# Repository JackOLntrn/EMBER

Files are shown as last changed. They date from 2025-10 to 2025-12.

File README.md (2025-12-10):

# EMBER
## Overview
The EMBER project makes use of the a thermal IR camera to detect fires on a pan/tilt motor mechanism. Once a fire is detected, the system points the thermal camera/hose nozzle at the detected fire and activates a solenoid to spray water at the detected fire. The system is supplied with water from a garden hose. This repository includes all of the relavant files for the project. 
| Directory | Contents|
| --- | --- |
| [EMBER/src](src/) | Contains the header and cpp files developed for the project |
| [EMBER/hardware/board](hardware/board) | Contains the schematic board and gerber files used to develop a custom PCB used for the project|
| [EMBER/hardware/mech](hardware/mech) | Contains the 3D model files of parts developed for the project |
| [EMBER/docs](docs/) | Contains doxygen generated documents for code documentation |

See board documentation [here](hardware/board/README.md)

See mechanical component documentation [here](hardware/mech/README.md)

See code documentation [here](https://jackolntrn.github.io/EMBER/)

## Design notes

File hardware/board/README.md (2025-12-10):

# EMBER Board Design

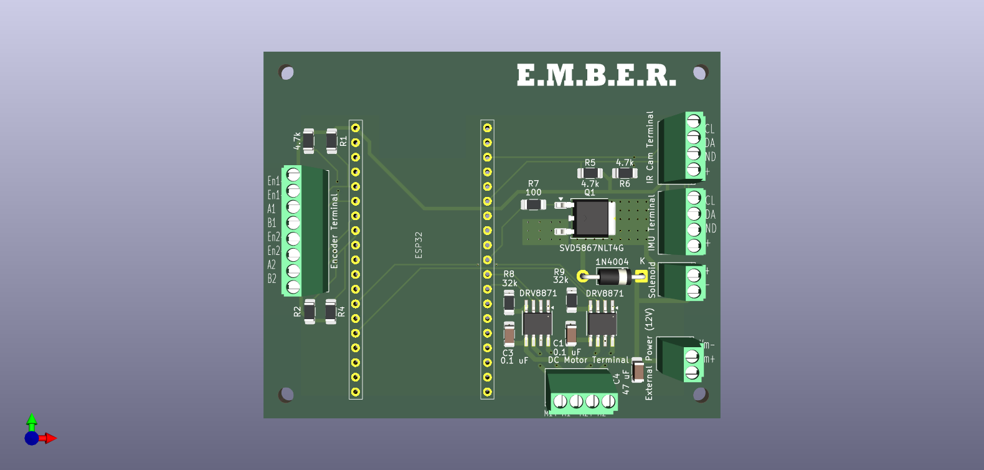
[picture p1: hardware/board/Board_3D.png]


This folder contains the schematic and pcb files for EMBER.

The board has the following terminals for connection to hardware:

| Terminal | Description |
| --- | --- |
| ESP32 Pin Connector | 28 pin connector for connection of ESP32 to the board. |
| Encoder Terminal | 8 position terminal for connection to the 2 motor quadrature encoders. Has 3.3V+ and gnd output for both terminals denoted by Eni+ and Eni- respectively. Has inputs for channels A and B. |
| DC Motor Terminal | 4 position terminal to connect the 2 motors. Ensure that motor 1's encoder is connected to channels A1 and B1 on the encoder terminal, and motor 2's encoder is connected to channels A2 and B2 on the encoder terminal. |
| IR Cam Terminal | 4 position terminal for I2C connection to the MLX90640 Thermal IR Camera. Has 3.3V+ and gnd output and SDA/SCL input. |
| IMU Terminal | 4 position terminal to support an additional I2C peripheral, for instance an IMU. Has 3.3V+ and gnd output and SDA/SCL input. |
|Solenoid | 2 position terminal for connection to the Solenoid. Outputs Vm+ and Vm- using a MOSFET controlled by the microcontroller with a flyback diode circuit. |
| External Power (12V) | 2 position terminal for connection to battery. Vm+ should be ~12V+ and Vm- should be gnd. |

### Board
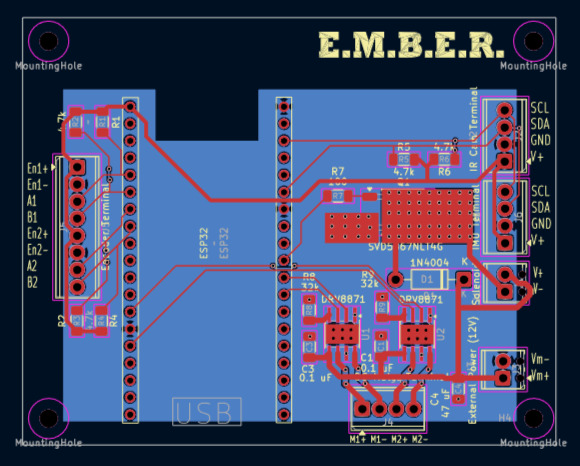
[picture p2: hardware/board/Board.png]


## Schematic
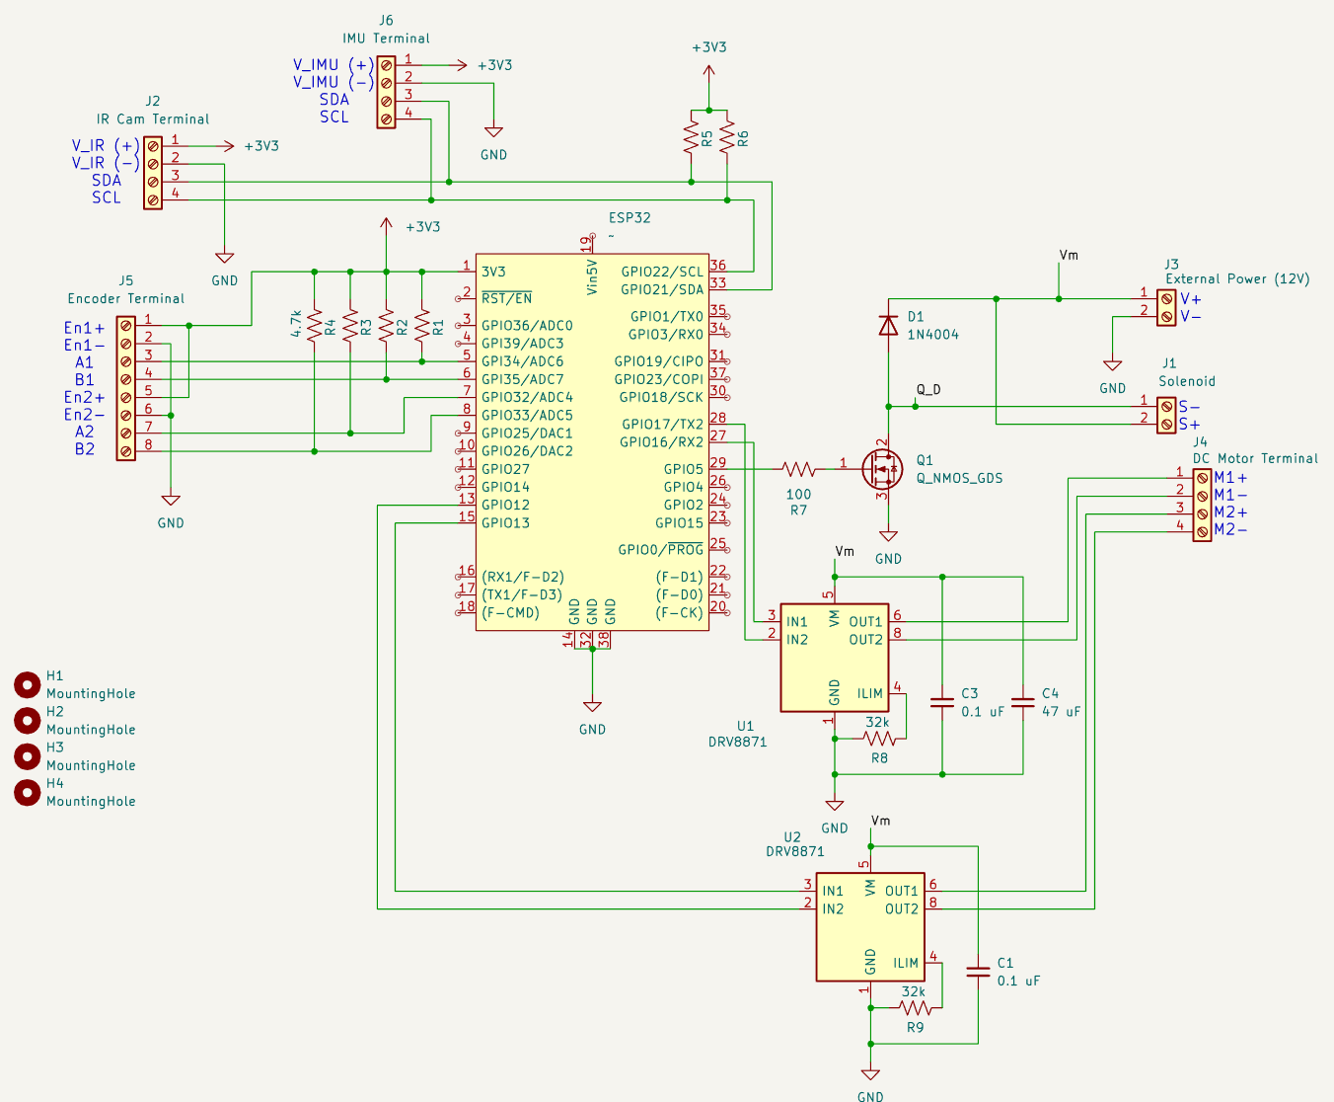
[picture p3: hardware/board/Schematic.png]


## Board Componenets

### 1. ESP32 NODEMCU-32S ESP-32S Kit x1
Main microcontroller for project - AliExpress: [NodeMCU ESP-32S](https://www.aliexpress.us/item/3256803993966716.html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)

### 2. DRV8871DDAR - Motor Driver x2
Motor driver with 2 inputs from controller for PWM control - Texas Instruments: [DRV8871DDAR](https://www.digikey.com/en/products/detail/texas-instruments/DRV8871DDAR/5639726)

### 3. 1N4004 Diode
Flyback Diode for Solenoid/MOSFET circuit : [1N4004-E3/54](https://www.digikey.com/en/products/detail/diotec-semiconductor/1N4004/13164524)

### 4. MOSFET N-CH x1
MOSFET to turn solenoid on/off from microcontroller N-Channel 60 V 22A (Tc) 3.3W (Ta), 43W (Tc) - Onsemi: [SVD5867NLT4G](https://www.digikey.com/en/products/detail/onsemi/SVD5867NLT4G/3062534)

### 5. 100Ω Resistor x1
Resistor between microcontroller and MOSFET gate - Vishay Dale: [TNPW1206100RBEEA](https://www.digikey.com/en/products/detail/vishay-dale/TNPW1206100RBEEA/1607739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)

### 6. 4.7kΩ Resistor x6
Pullup Resistors for I2C circuit and Encoder Channels - YAGEO: [RC1206FR-074K7L](https://www.digikey.com/en/products/detail/yageo/RC1206FR-074K7L/728887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)

### 7. 32kΩ Resistor x2
Current limit resistor for motor drivers (limitting to 2A, under the motor stall current to protect motors) - KOA Speer Electronics, Inc: [RN73H2BTTD3202F100](https://www.digikey.com/en/products/detail/koa-speer-electronics-inc/RN73H2BTTD3202F100/10098378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)

### 8. 47μF Capacitor x1
Filter capacitor for motor drivers - TDK Corporation: [C3216X5R1E476M160DC](https://www.digikey.com/en/products/detail/tdk-corporation/C3216X5R1E476M160DC/22106052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)

### 9. 0.1μF Capacitor x2
Filter capacitor for motor drivers - KEMET: [C1206C104K5RACTU](https://www.digikey.com/en/products/detail/kemet/C1206C104K5RACTU/411248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)

### 10. 2 Position Screw Terminal x2
12V power in and Solenoid power out terminals - Phoenix Contact: [1725656](https://www.digikey.com/en/products/detail/phoenix-contact/1725656/267462)

### 11. 4 Position Screw Terminal x3
I2C connections (2 were added for potential to integrate another I2C peripheral such as an IMU, although only 1 is used for Thermal IR camera), and motor output connection - Phoenix Contact: [1725672](https://www.digikey.com/en/products/detail/phoenix-contact/1725672/267464)

### 12. 8 Position Screw Terminal x1
Encoder connections - Phoenix Contact: [1725711](https://www.digikey.com/en/products/detail/phoenix-contact/1725711/267468)

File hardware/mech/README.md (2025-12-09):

EMBER Mechanical Components 
======
This folder contains the mechanical assembly for EMBER and its associated components. 

Custom Solidworks Files
------

### [1. EMBER Assembly](../mech/EMBER.SLDASM)
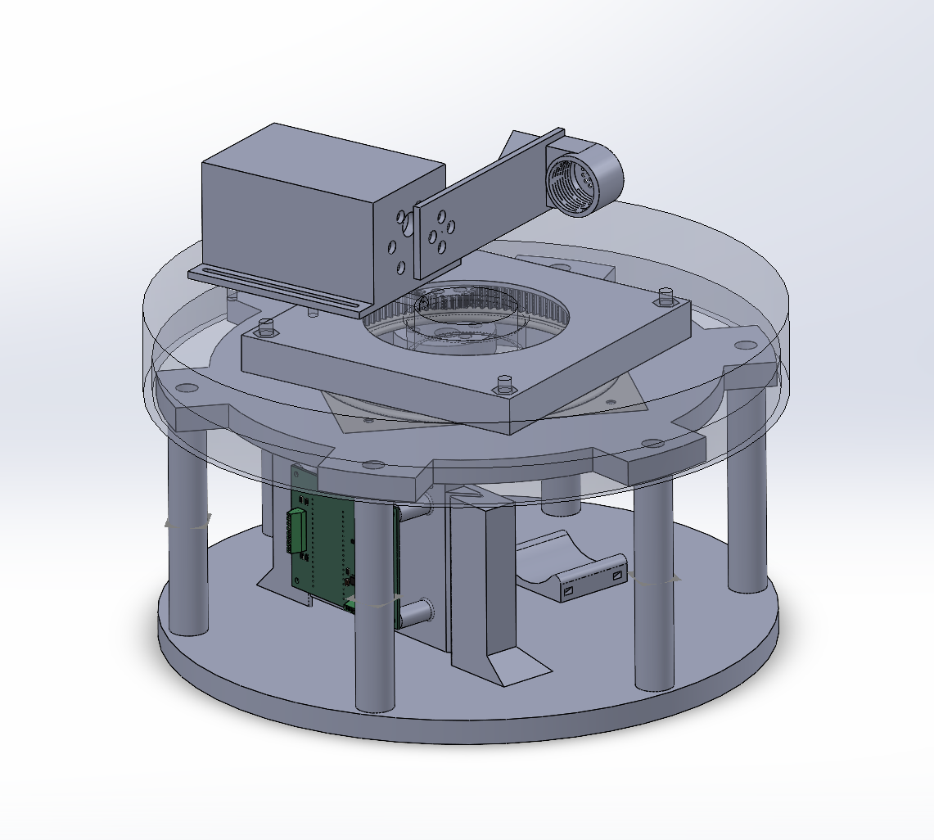
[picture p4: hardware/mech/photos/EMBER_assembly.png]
Solidworks Assembly View


The main assembly file, contains all the relevant piece parts mated to visualize real world model.

### 2. EMBER Board
Model of the custom PCB exported from KiCAD for fitting.

QTY: 1

### 3. EMBER Base Enclosure
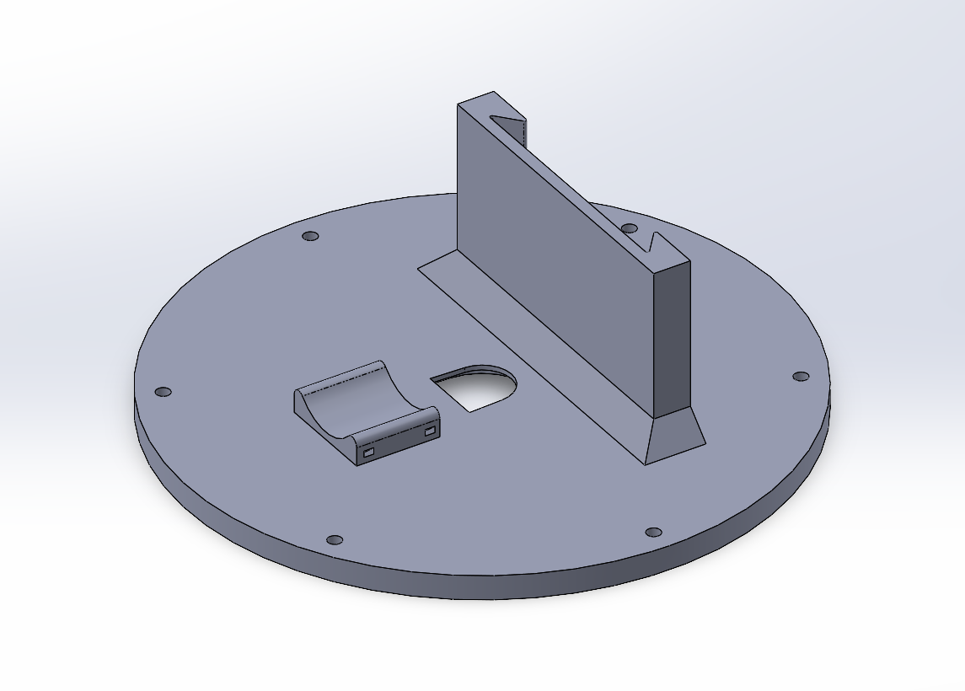
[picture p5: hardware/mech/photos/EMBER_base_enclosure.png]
Base Enclosure


Main part that seats all parts and holds the solenoid valve.

QTY: 1

### 4. EMBER Base Lid 1
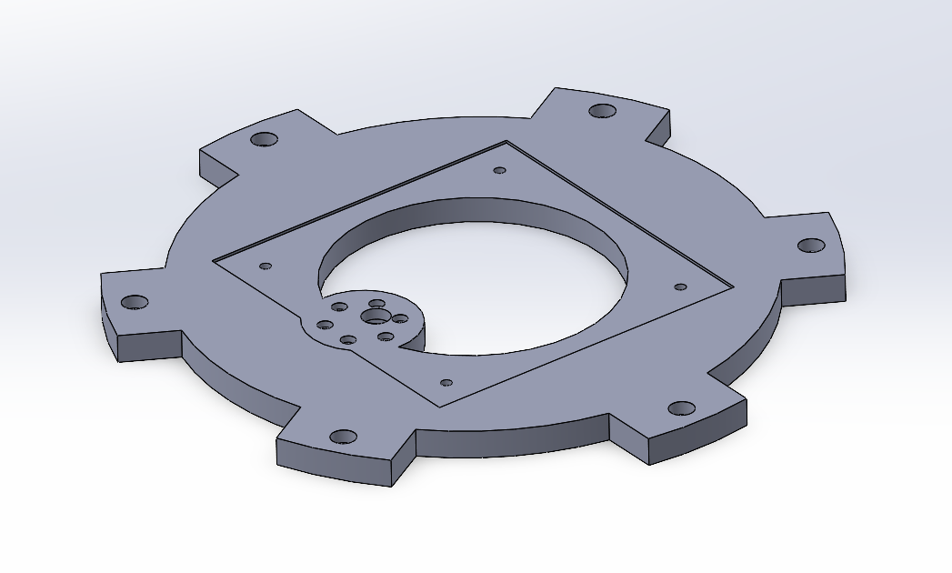
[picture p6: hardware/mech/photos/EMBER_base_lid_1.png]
Base Lid 1


Large circular plate that mounts the pan motor and connects enclosure supports to the turntable.

QTY: 1

### 5. EMBER Board Mount
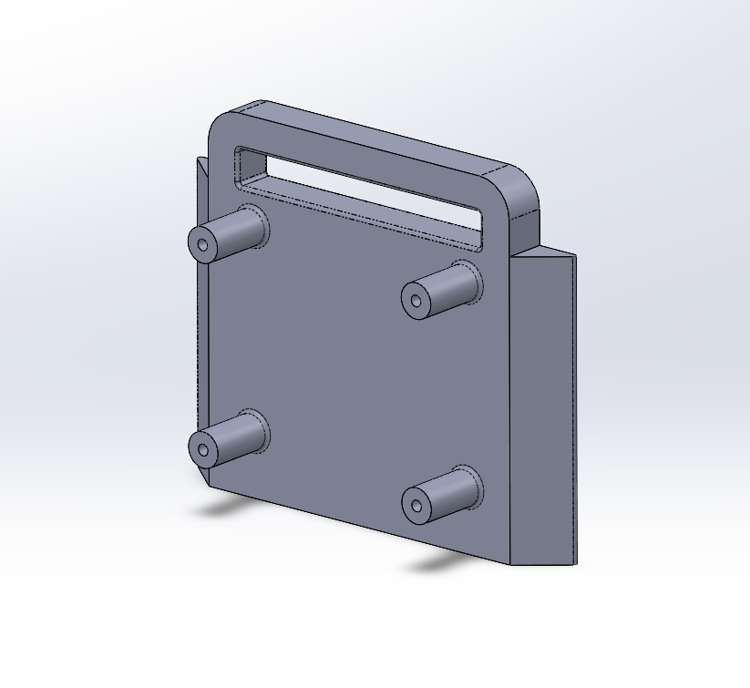
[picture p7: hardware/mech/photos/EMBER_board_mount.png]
Board Mount


Piece that has standoffs for the PCB and holds in place using dovetail slot on base enclosure.

QTY: 1

### 6. EMBER Enclosure Supports
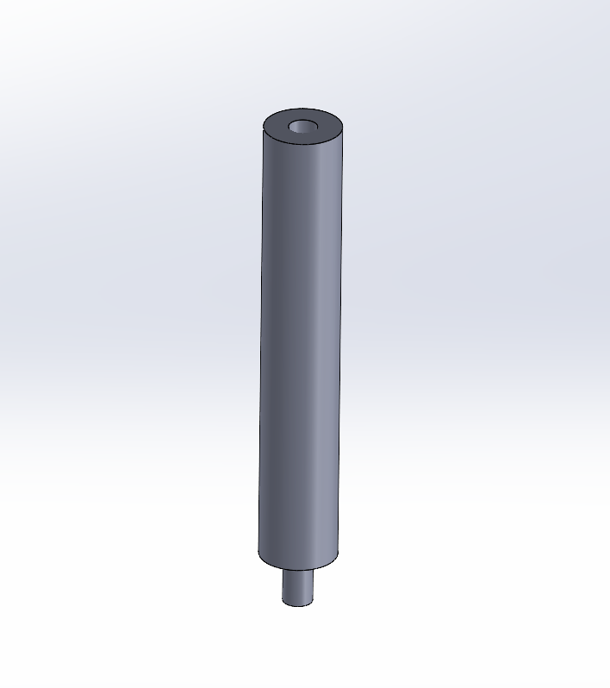
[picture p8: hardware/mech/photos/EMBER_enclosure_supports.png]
Enclosure Support


Supports all components connected to the upper base lid and above.

QTY: 6

### 7. EMBER Hose Boom Arm
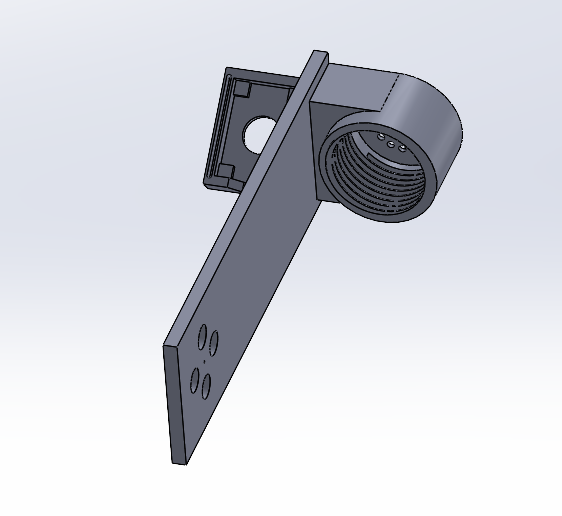
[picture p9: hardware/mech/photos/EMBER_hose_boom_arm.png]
Hose Boom Arm


Mechanical arm that mounts to tilt motor D shaft coupling and mounts IR camera and flexible hose end.

QTY: 1

### 8. EMBER Hose Nozzle
Test file to ensure threads fit the purchased mechanical parts. Not in final assembly.

QTY: 1

### 9. EMBER IR Camera Cover
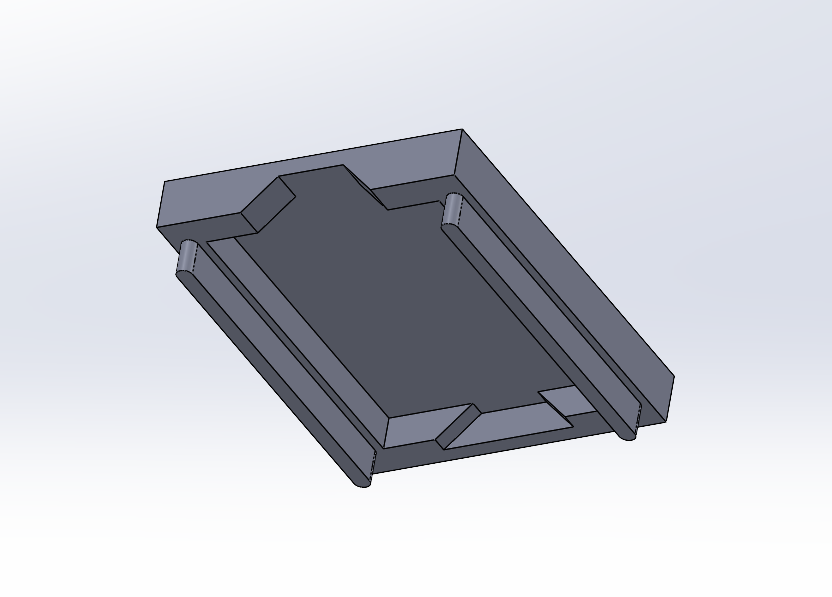
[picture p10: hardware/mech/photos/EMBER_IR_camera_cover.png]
IR Camera Cover


Snap fit cover for the IR camera when seated into the hose boom arm.

QTY: 1

### 10. EMBER Pan Motor Gear
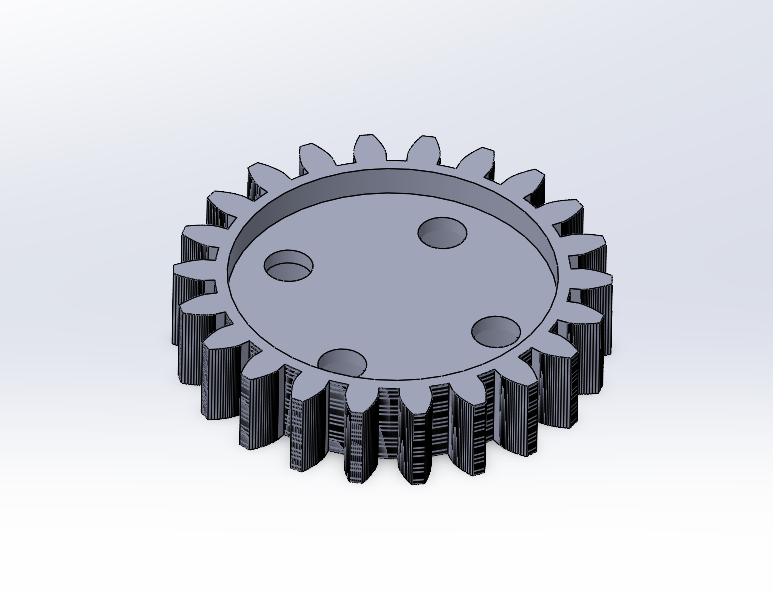
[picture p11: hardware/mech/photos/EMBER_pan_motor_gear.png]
Pan Motor Gear


22-tooth external gear mounted to pan motor D shaft coupling and rotates with the internal teeth on top platform.

QTY: 1

### 11. EMBER Tilt Motor Mount
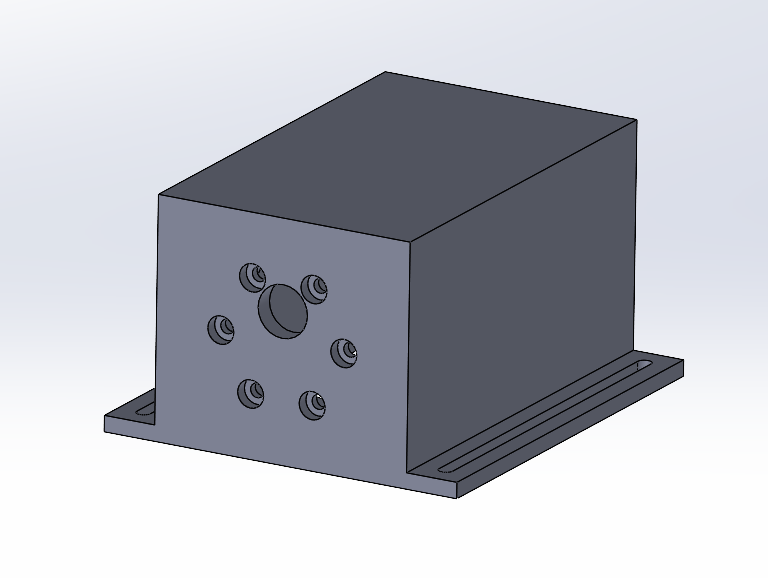
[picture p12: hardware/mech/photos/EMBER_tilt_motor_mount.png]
Tilt Motor Mount


Tilt motor mounting that has slots and fastened onto top platform with motor mount. 

QTY: 1

### 12. EMBER Top Platform with Motor Mount
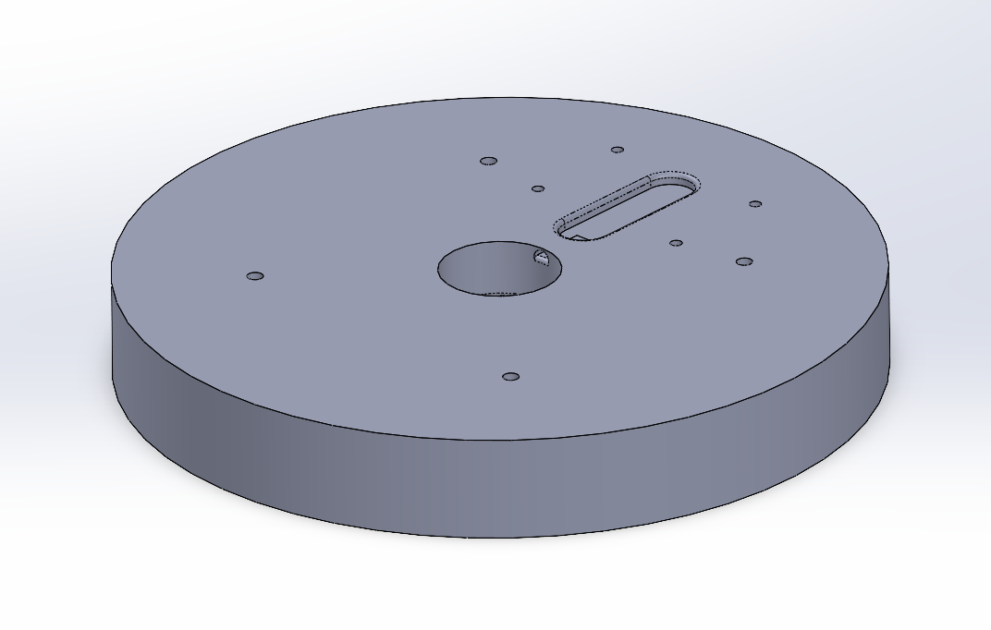
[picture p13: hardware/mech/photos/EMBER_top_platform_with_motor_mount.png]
Top Platform with Motor Mount


Cover that seats above top platform and has features to connect tilt motor mount onto it.

QTY: 1

### 13. EMBER Top Platform
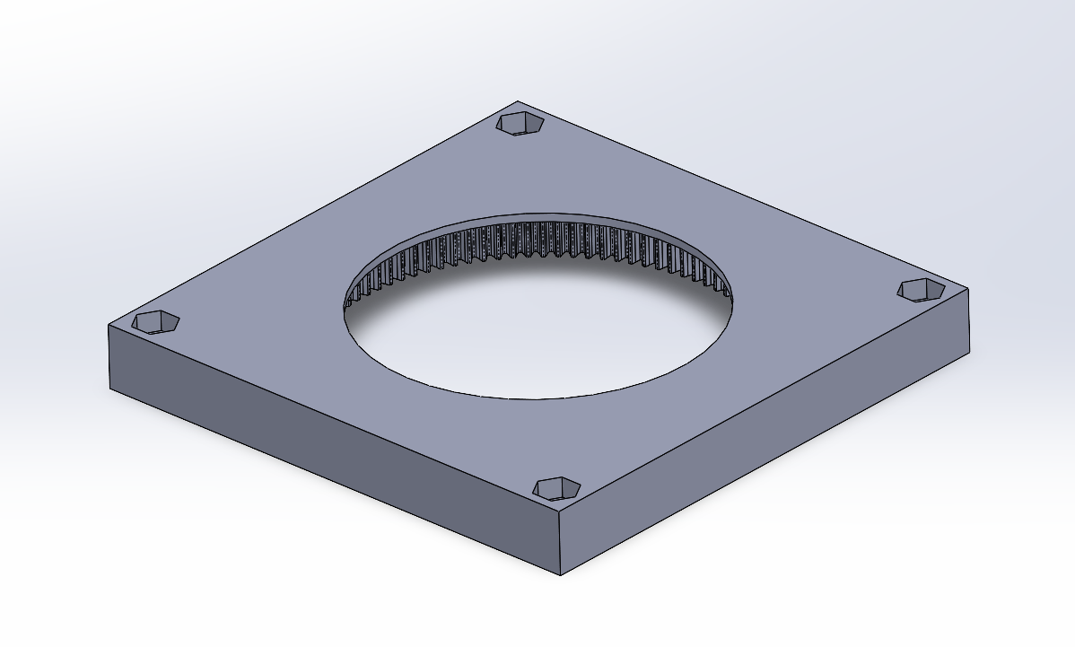
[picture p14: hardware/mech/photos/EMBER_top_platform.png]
Top Platform


Internal teeth gear that mounts onto top of lubricated turntable. 

QTY: 1

### 14. 1544T1 Lubricated Turntable
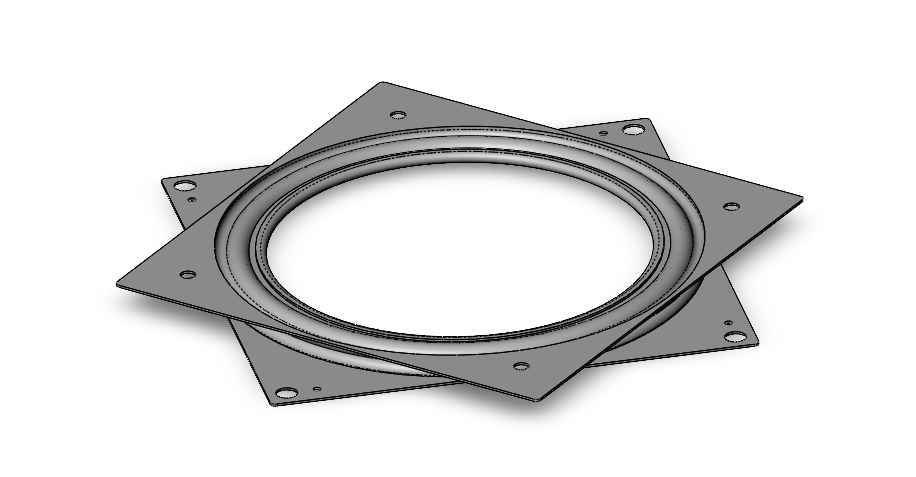
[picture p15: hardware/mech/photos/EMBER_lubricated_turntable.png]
Lubricated Turntable


Turntable from McMaster Carr used to minimize friction on pan mechanism. 

QTY: 1

Electrical Hardware
------

### [1. 3/4" 12V DC Solenoid Valve - Brass Body Normally Closed, VITON SEAL](https://ussolid.com/products/u-s-solid-electric-solenoid-valve-3-4-12v-dc-solenoid-valve-brass-body-normally-closed-viton-seal-html)
Solenoid valve that connects household hose to internal pipe fittings.

QTY: 1

### [2. 37GB-3530-EN Motor](../mech/37GB-3530-EN_Motor_Spec_Sheet.pdf)
Specification sheet for our selected 12V motor.

QTY: 2

### [3. Adafruit MLX90640 IR Thermal Camera Breakout - 55 Degree](https://www.adafruit.com/product/4407#description)
IR Thermal Camera product page and description.

QTY: 1

Mechanical Hardware
------

### [1. 3/4 in. MNPT x FHT PVC Swivel](https://www.homedepot.com/p/Orbit-3-4-in-MNPT-x-FHT-PVC-Swivel-53364/100197786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)
Connects common household hose to solenoid valve and the solenoid valve to the internal hose.

QTY: 2

### [2. 1/2 in. Barb x 3/4 in. MIP Nylon Adapter Fitting](https://www.homedepot.com/p/Everbilt-1-2-in-Barb-x-3-4-in-MIP-Nylon-Adapter-Fitting-800229/300862694)
Connects solenoid valve to flexible hose and flexible hose to mechanical arm.

QTY: 2

### [3. 1/2 in. I.D. x 5/8 in. O.D. x 10 ft. Clear Vinyl Tubing](https://www.homedepot.com/p/Everbilt-1-2-in-I-D-x-5-8-in-O-D-x-10-ft-Clear-Vinyl-Tubing-T10006010/304185142)
Flexible hose that fits into the nylon barb adapter and supplies water from the hosehold hose to our target.

QTY: 1

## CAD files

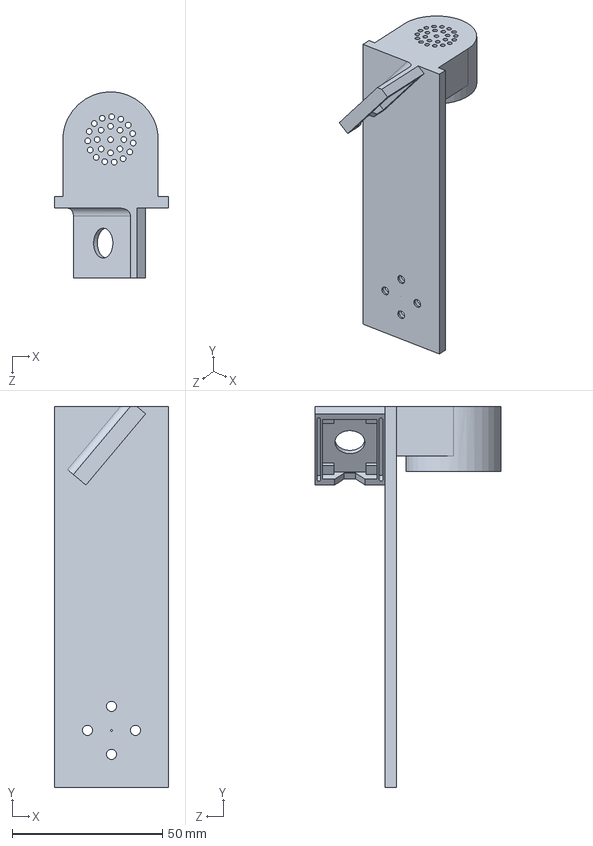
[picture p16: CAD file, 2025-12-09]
hardware/mech/EMBER_Hose Boom Arm.SLDPRT
38.1 x 127.0 x 62.0 mm

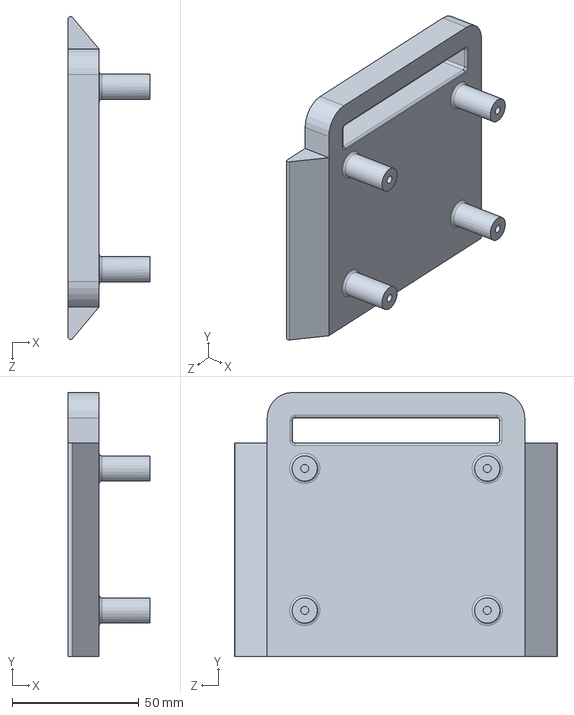
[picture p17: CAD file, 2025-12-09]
hardware/mech/EMBER_Board Mount.SLDPRT
32.3 x 104.2 x 127.4 mm

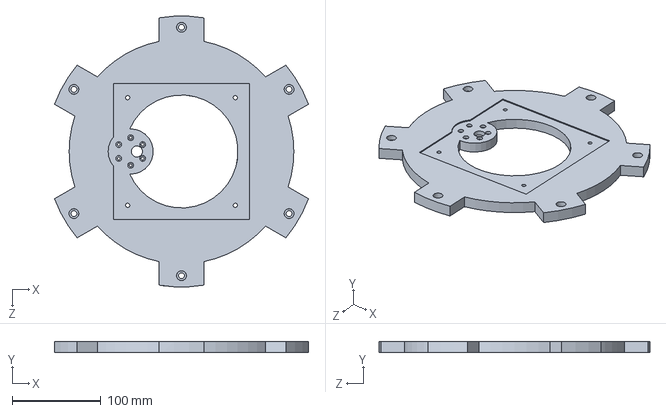
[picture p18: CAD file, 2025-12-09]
hardware/mech/EMBER_Base Lid 1.SLDPRT
285.7 x 12.7 x 304.3 mm

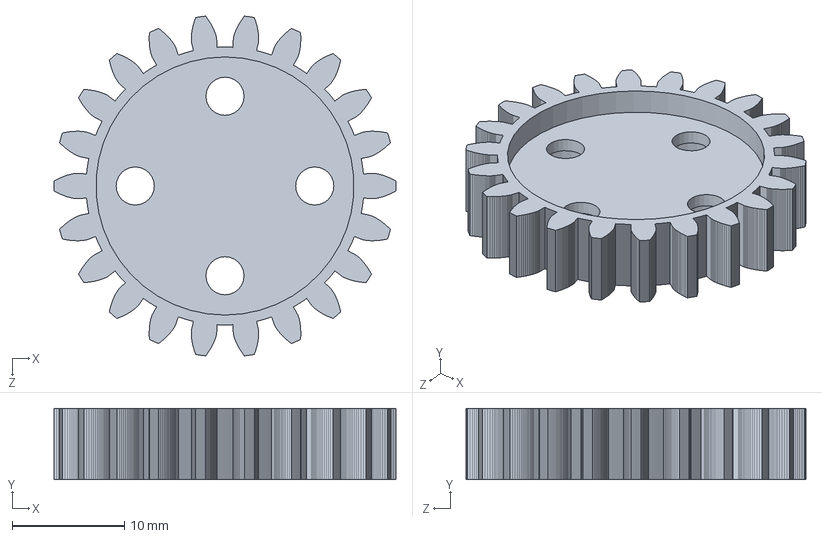
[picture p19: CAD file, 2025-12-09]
hardware/mech/EMBER_Pan Motor Gear.SLDPRT
30.5 x 6.35 x 30.3 mm

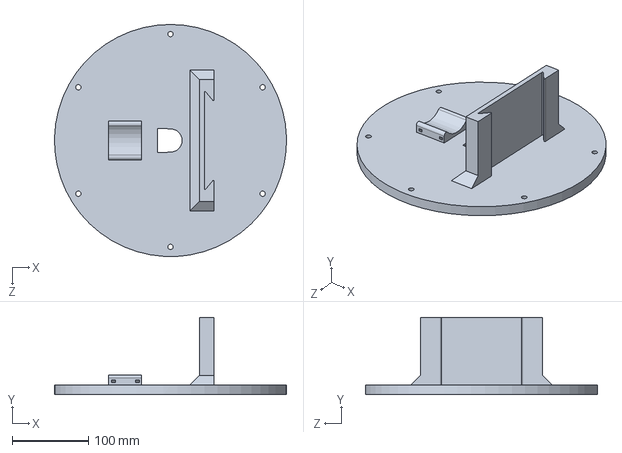
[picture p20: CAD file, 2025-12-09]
hardware/mech/EMBER_Base Enclosure.SLDPRT
304.7 x 101.6 x 304.8 mm

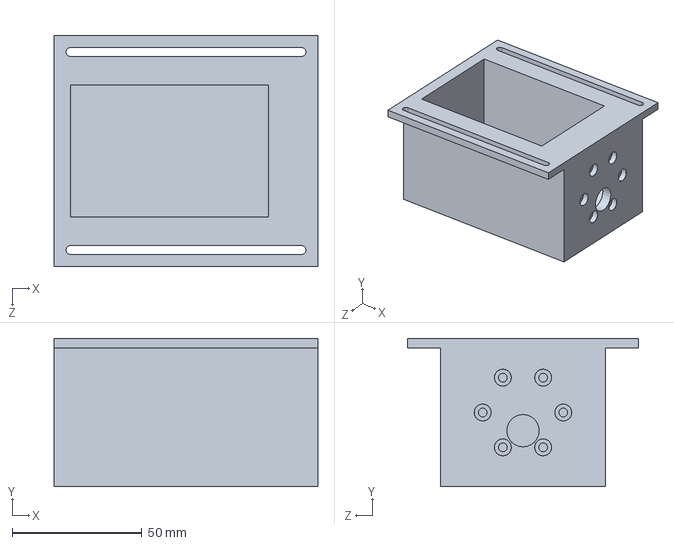
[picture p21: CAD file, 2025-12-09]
hardware/mech/EMBER_Tilt Motor Mount.SLDPRT
101.6 x 57.1 x 88.9 mm

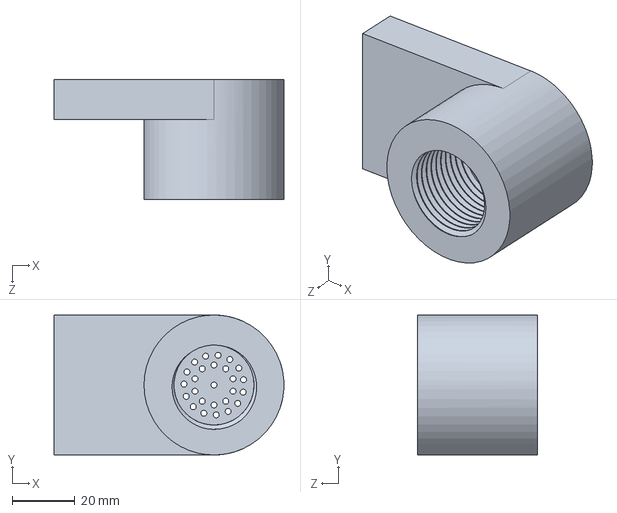
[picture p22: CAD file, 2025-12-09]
hardware/mech/EMBER_Hose Nozzle.SLDPRT
73.0 x 44.5 x 38.1 mm

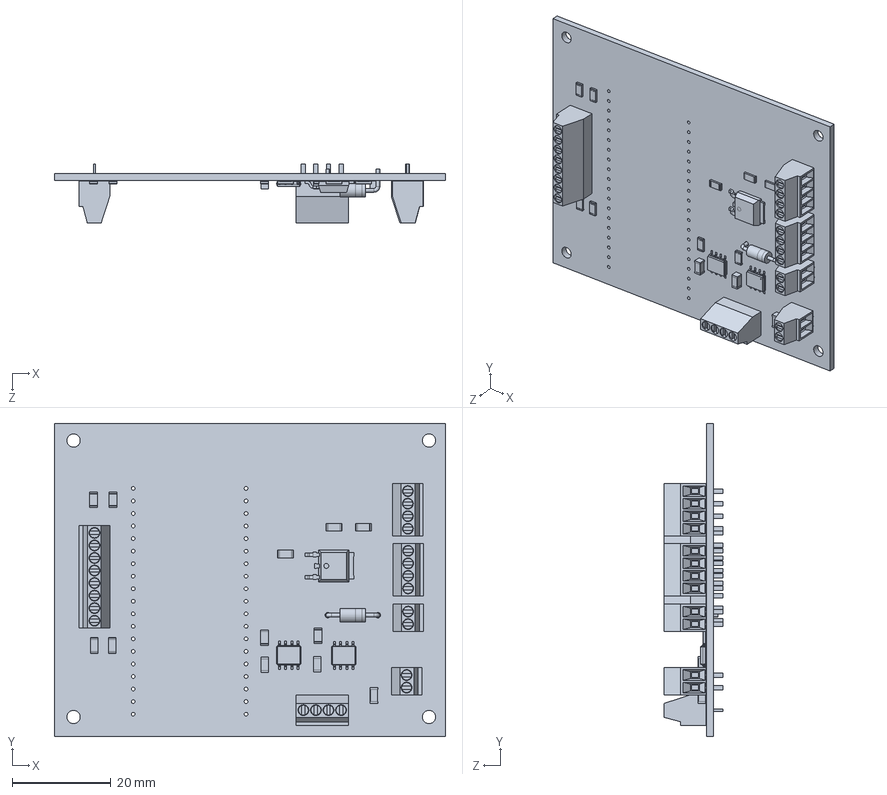
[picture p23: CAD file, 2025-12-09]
hardware/mech/EMBER_BOARD.SLDPRT
79.2 x 63.5 x 12.0 mm

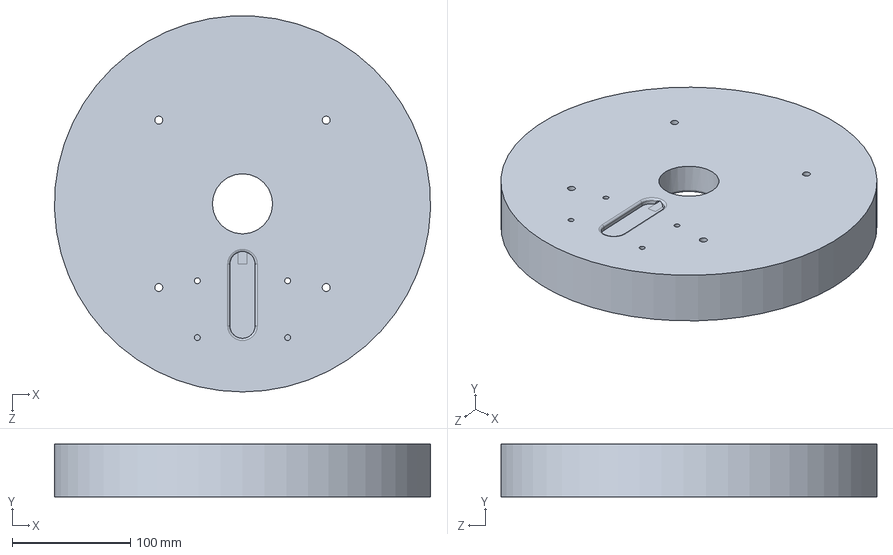
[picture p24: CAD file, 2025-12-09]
hardware/mech/EMBER_Top Platform with Motor Mount.SLDPRT
317.4 x 44.5 x 317.2 mm

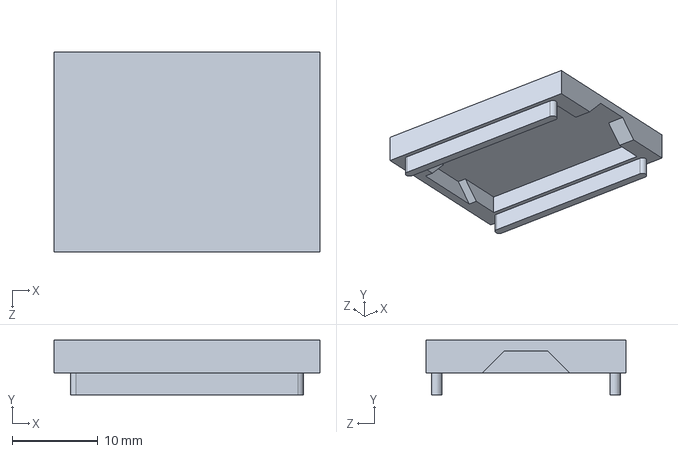
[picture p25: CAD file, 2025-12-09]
hardware/mech/EMBER_IR Camera Cover.SLDPRT
31.0 x 6.35 x 23.3 mm

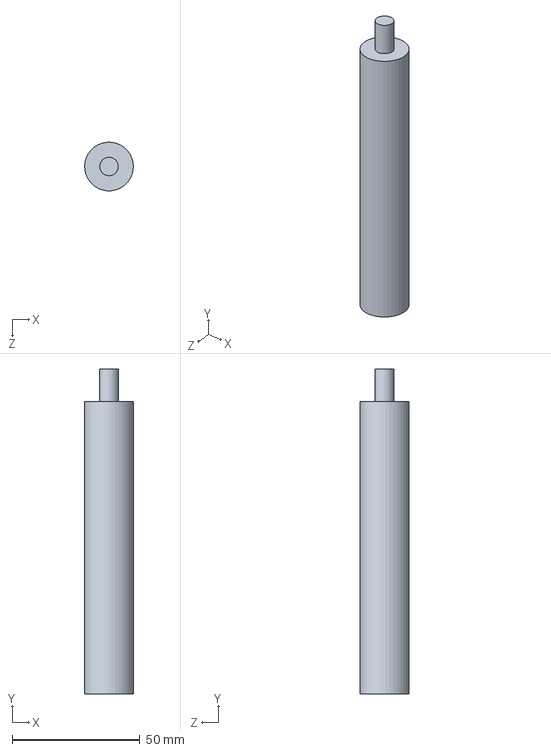
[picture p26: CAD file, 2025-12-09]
hardware/mech/EMBER_Enclosure Supports.SLDPRT
19.0 x 127.0 x 19.1 mm

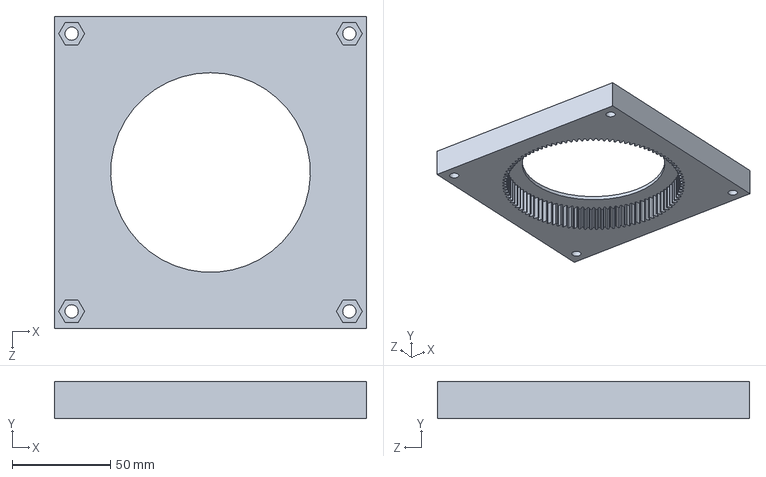
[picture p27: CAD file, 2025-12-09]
hardware/mech/EMBER_Top Platform.SLDPRT
158.8 x 19.1 x 158.8 mm

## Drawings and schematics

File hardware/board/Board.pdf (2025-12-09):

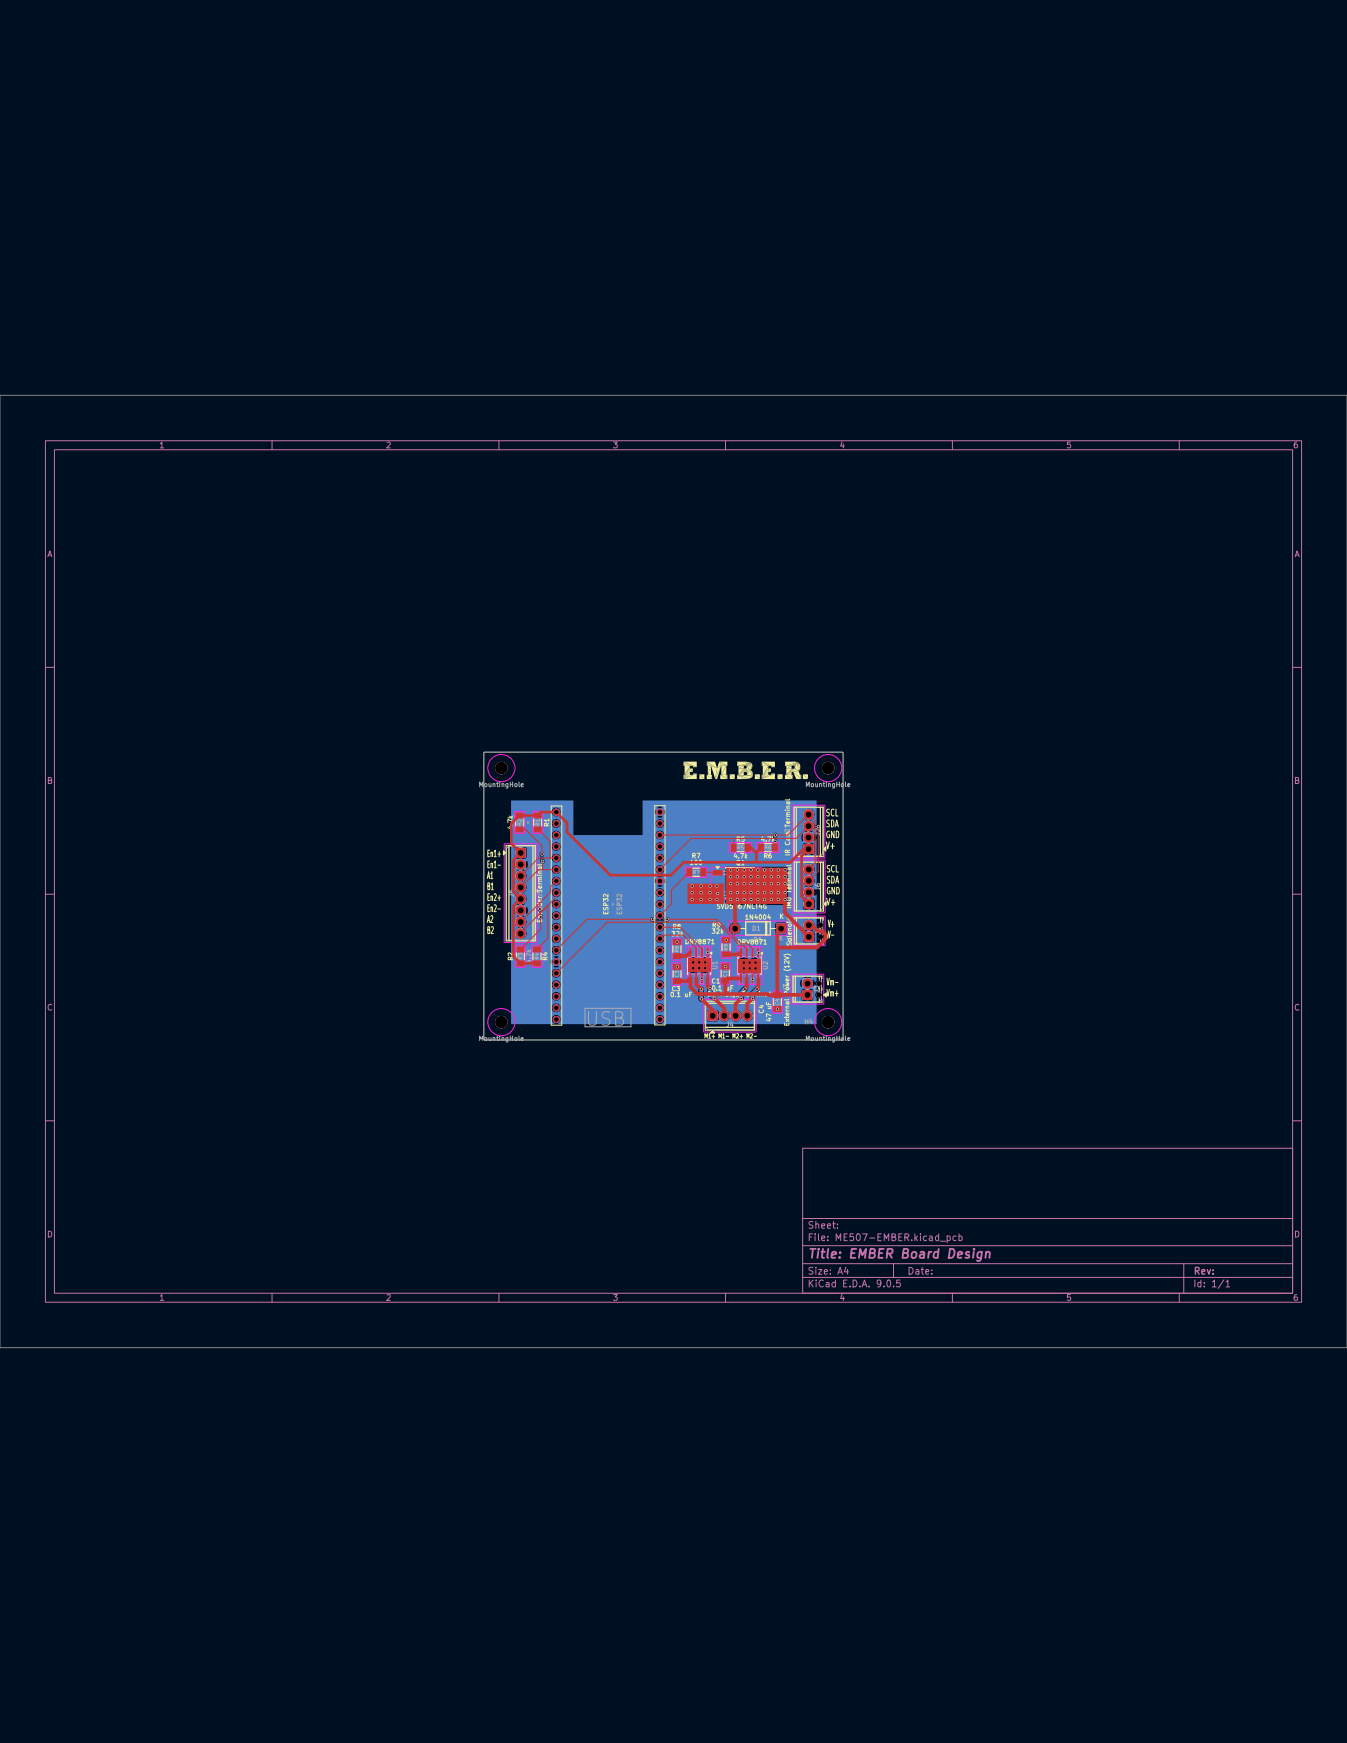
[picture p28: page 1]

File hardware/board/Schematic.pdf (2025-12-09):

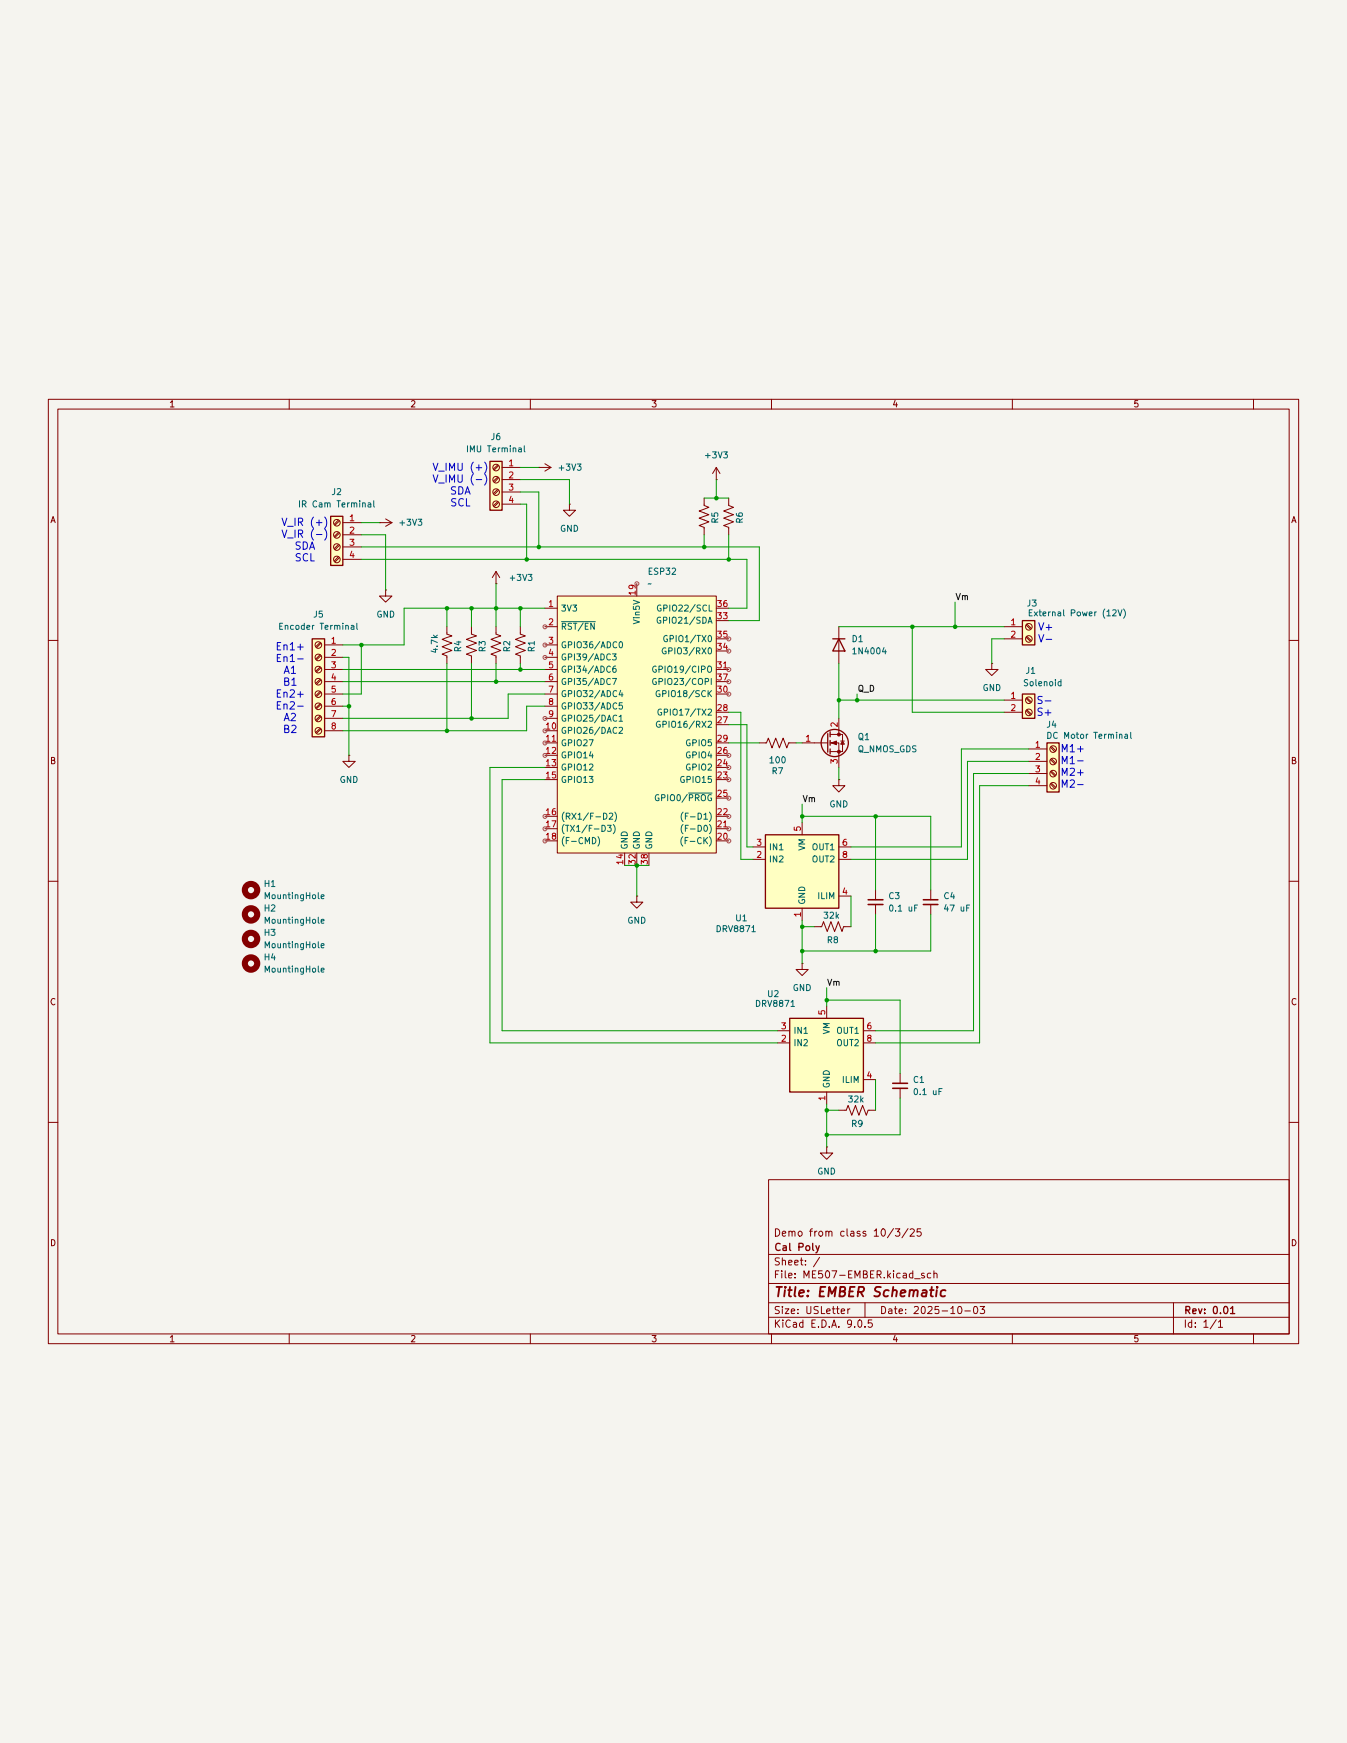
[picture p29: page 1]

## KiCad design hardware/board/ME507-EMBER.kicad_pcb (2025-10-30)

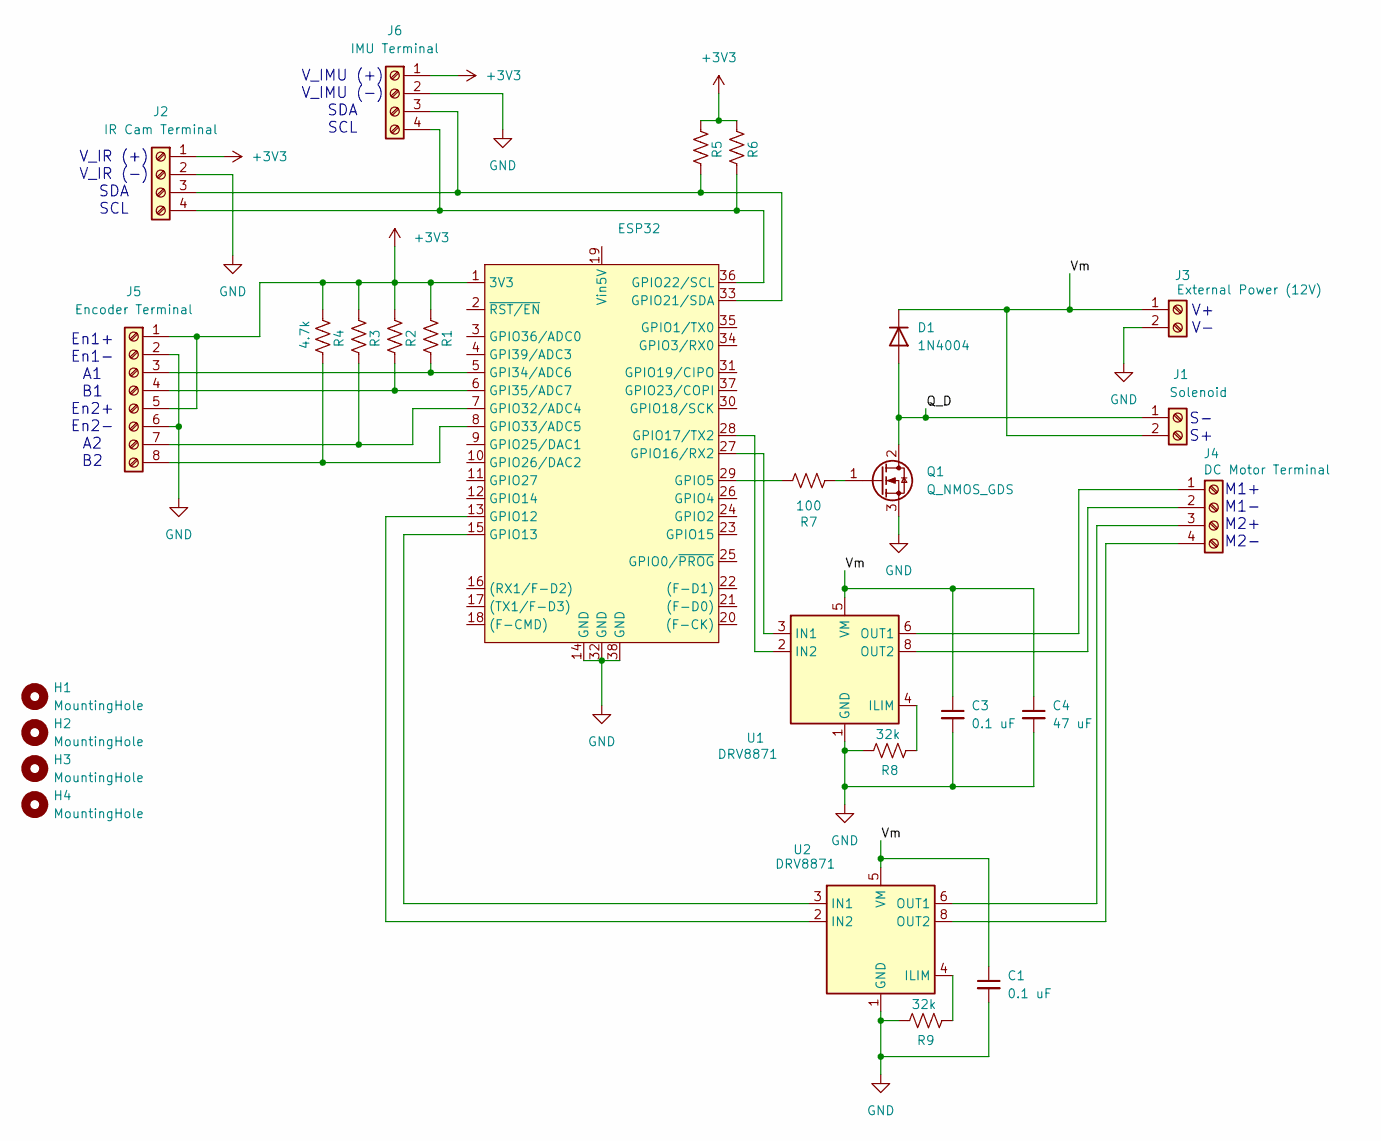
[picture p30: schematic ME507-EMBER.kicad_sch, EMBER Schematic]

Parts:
C1, C3: 0.1 uF; C_1206_3216Metric_Pad1.33x1.80mm_HandSolder
C4: 47 uF; C_1206_3216Metric_Pad1.33x1.80mm_HandSolder
D1: 1N4004; D_DO-41_SOD81_P10.16mm_Horizontal
ESP32: ESP32_NodeMCU_KeeYees
H1, H2, H3, H4: MountingHole; MountingHole_2.7mm_M2.5
J1: Solenoid; TerminalBlock_Phoenix_MPT-0,5-2-2.54_1x02_P2.54mm_Horizontal
J2: IR Cam Terminal; TerminalBlock_Phoenix_MPT-0,5-4-2.54_1x04_P2.54mm_Horizontal
J3: External Power (12V); TerminalBlock_Phoenix_MPT-0,5-2-2.54_1x02_P2.54mm_Horizontal
J4: DC Motor Terminal; TerminalBlock_Phoenix_MPT-0,5-4-2.54_1x04_P2.54mm_Horizontal
J5: Encoder Terminal; TerminalBlock_Phoenix_MPT-0,5-8-2.54_1x08_P2.54mm_Horizontal
J6: IMU Terminal; TerminalBlock_Phoenix_MPT-0,5-4-2.54_1x04_P2.54mm_Horizontal
Q1: Q_NMOS_GDS; TO-252-2
R1, R2, R3, R5, R6: R_1206_3216Metric_Pad1.30x1.75mm_HandSolder
R4: 4.7k; R_1206_3216Metric_Pad1.30x1.75mm_HandSolder
R7: 100; R_1206_3216Metric_Pad1.30x1.75mm_HandSolder
R8, R9: 32k; R_1206_3216Metric_Pad1.30x1.75mm_HandSolder
U1, U2: DRV8871; Texas_HTSOP-8-1EP_3.9x4.9mm_P1.27mm_EP2.95x4.9mm_Mask2.4x3.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

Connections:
+3V3: ESP32.1 (3V3), J2.1, J5.1, J5.5, J6.1, R1.2, R2.2, R3.2, R4.2, R5.2, R6.2
/Q_D: D1.2 (A), J1.1, Q1.2 (D)
/Vm: C1.1, C3.1, C4.1, D1.1 (K), J1.2, J3.1, U1.5 (VM), U2.5 (VM)
GND: C1.2, C3.2, C4.2, ESP32.14 (GND), ESP32.32 (GND), ESP32.38 (GND), J2.2, J3.2, J5.2, J5.6, J6.2, Q1.3 (S), R8.1, R9.1, U1.1 (GND), U1.7 (GND), U1.9 (GND), U2.1 (GND), U2.7 (GND), U2.9 (GND)
unnamed: ESP32.5 (GPI34/ADC6), J5.3, R1.1
unnamed: ESP32.6 (GPI35/ADC7), J5.4, R2.1
unnamed: ESP32.29 (GPIO5), R7.1
unnamed: ESP32.13 (GPIO12), U2.2 (IN2)
unnamed: ESP32.15 (GPIO13), U2.3 (IN1)
unnamed: ESP32.27 (GPIO16/RX2), U1.3 (IN1)
unnamed: ESP32.28 (GPIO17/TX2), U1.2 (IN2)
unnamed: ESP32.33 (GPIO21/SDA), J2.3, J6.3, R5.1
unnamed: ESP32.36 (GPIO22/SCL), J2.4, J6.4, R6.1
unnamed: ESP32.7 (GPIO32/ADC4), J5.7, R3.1
unnamed: ESP32.8 (GPIO33/ADC5), J5.8, R4.1
unnamed: J4.1, U1.6 (OUT1)
unnamed: J4.2, U1.8 (OUT2)
unnamed: J4.3, U2.6 (OUT1)
unnamed: J4.4, U2.8 (OUT2)
unnamed: Q1.1 (G), R7.2
unnamed: R8.2, U1.4 (ILIM)
unnamed: R9.2, U2.4 (ILIM)

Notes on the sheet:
M1+ M1- M2+ M2-
V+ V-
En1+ En1- A1 B1 En2+ En2- A2 B2
S- S+
V_IR (+) V_IR (-) SDA SCL
V_IMU (+) V_IMU (-) SDA SCL

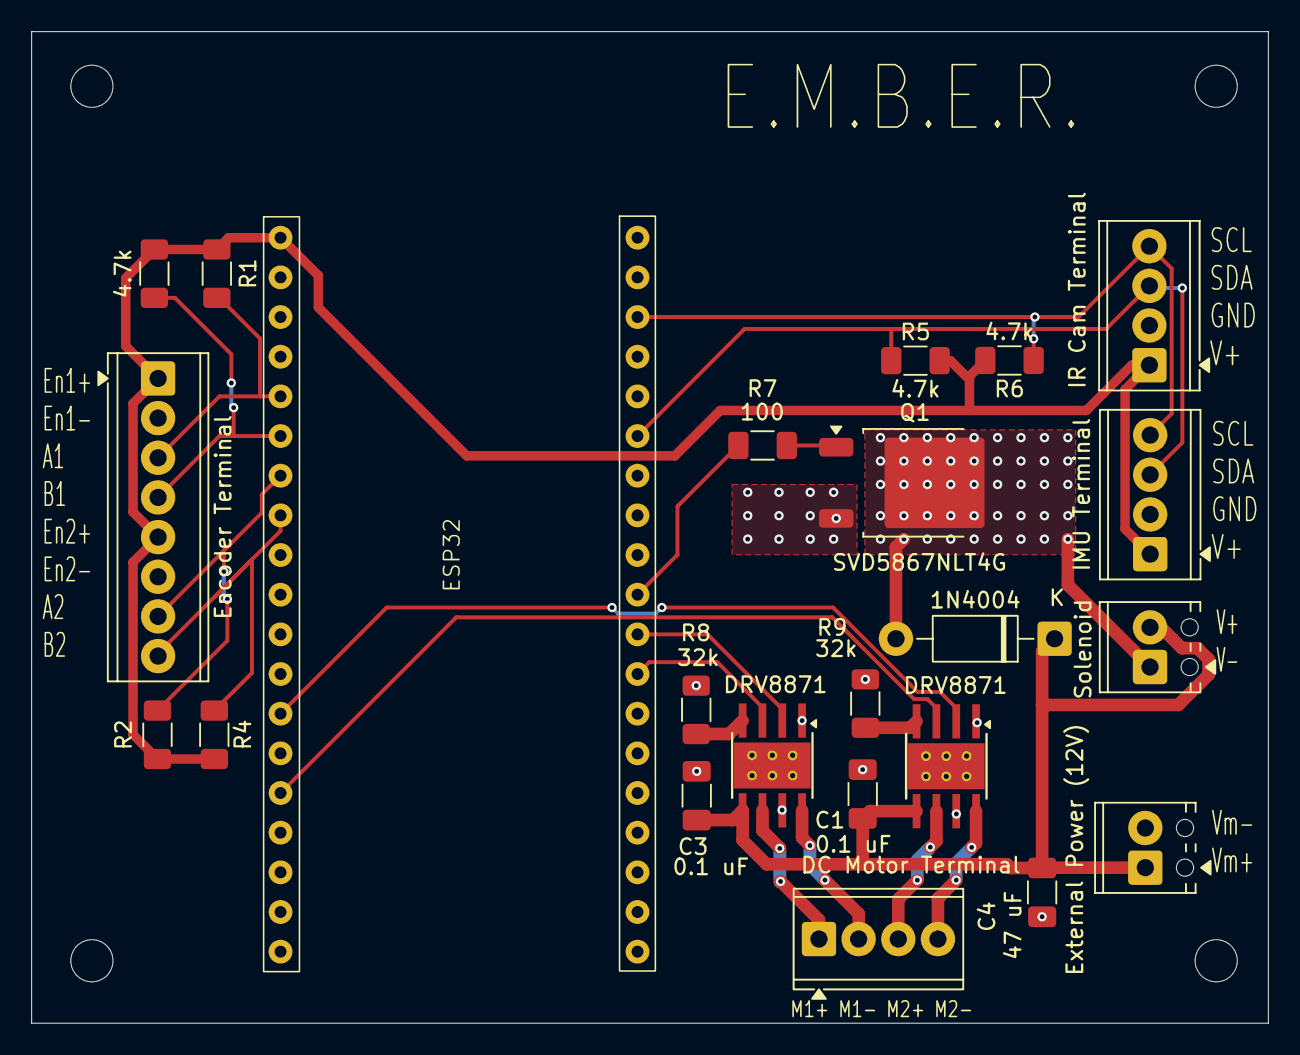
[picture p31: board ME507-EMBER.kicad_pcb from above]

Board: 2 copper layers, 79.2 x 63.5 mm, 27 parts (0 on the bottom side), 22 nets.

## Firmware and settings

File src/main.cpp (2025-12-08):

/** 
 * E.M.B.E.R - main file
 * @author Jackson Cordova, Matthieu Gol, GPT-5 mini
 * @date November 2025
 * @description: Main file for the E.M.B.E.R project, initializes tasks and hardware components
 */
#include <Arduino.h>
#include "PrintStream.h"
#include "shares.h"
#include "taskshare.h"
#include "DRV8871Driver.h"
#include <adafruit_mlx90640.h>
#include <ESP32Encoder.h>
#include "task_motorControl.h"
#include "task_read_camera.h"
#include "task_webserver.h"
#include "task_stateMachine.h"

Share<int32_t> panRefCount("PanRefCount");
Share<int32_t> tiltRefCount("TiltRefCount");
Share<bool> fire("Fire");
Share<bool> spray("Spray");
Share<uint16_t> hotIndex("HotIndex");
Share<uint8_t> systemState("SystemState");
ESP32Encoder enc1;
ESP32Encoder enc2;
float Frame[768];
DRV8871Driver Motor1(16,17);
DRV8871Driver Motor2(12,13);

/** @brief Setup function that runs once at start of code and initializes tasks
 */
void setup() {
    
    pinMode(5, OUTPUT);
    digitalWrite(5, LOW);
    delay(1000);

    Motor2.brakeMotor();
    Motor1.brakeMotor();
    Serial.begin(115200);
    while(!Serial);
    delay(100);
    xTaskCreate(task_motorControl,"Motor Control Task",
                4096,
                NULL,
                5,
                NULL);
    xTaskCreate(task_read_camera,
                "Read Camera Task",
                8192,
                NULL,
                7,
                NULL);
    setup_wifi();
    xTaskCreate(task_webserver,"IoT Task",8192,NULL,1,NULL);

    xTaskCreate(task_stateMachine,
                "State Machine Task",
                4096,
                NULL,
                4,
                NULL);
}

/** @brief Loop function for Arduino framework - not used as tasks are created in setup()
 */
void loop() {
  vTaskDelay(60000);
}

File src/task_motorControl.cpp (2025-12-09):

/** @file task_motorControl.cpp
 * 
 * @brief Motor control task for pan and tilt
 * @author Jackson Cordova, GPT5-mini
 * @date November 2025
 */

#include "task_motorControl.h"
#include <Arduino.h>
#include "DRV8871Driver.h"
#include <ESP32Encoder.h>
#include "PrintStream.h"
#include "shares.h"
#include <Preferences.h>

#define MAXSPEED 220
#define DEADBAND 10
#define Kp1 7
#define Kd1 4
#define Kp2 7
#define Kd2 4


 
 /** @brief task which controls the pan and tilt motors
  * @details This task reads the reference counts for pan and tilt from shares
  * as well as checks if a fire is present. When no fire is present, the task
  * uses a velocity control loop to sweep the pan motor back and forth between
  * its limits (180 degrees left and right). When a fire is detected, the task
  * switches to position control mode to move the pan and tilt motors to the
  * desired reference positions denoted by the reference counts from the shares.
  * The task uses proportional-derivative (PD) control for position control, and
  * proportional-integral-derivative (PID) control for velocity control during scanning.
  * The task has a period of 10 ms.
  * 
  * @param p_params not used and should be set to void in the xTaskCreate call
  */
 void task_motorControl(void* p_params) {

    
    //initialize motors and encoders
    
    enc2.attachHalfQuad(32,33);
    enc1.attachHalfQuad(34,35);
    // ensure motors are stopped at startup
    Motor1.brakeMotor();
    Motor2.brakeMotor();

    int32_t panErr, tiltErr, rawPRC, rawTRC;
    int32_t P1, D1, P2, D2;
    P1 = 0;
    P2 = 0;
    int16_t panSpeed, tiltSpeed;
    
    // Scanning mode state
    static bool moveToMax = true; // direction flag for velocity sweep
    static long prevPanCount = 0;
    static float prevErr = 0;
    static float integralErr = 0;  // integral of velocity error
    const float Kpv = 10.0f;  // velocity proportional gain
    const float Kdv = 0.0f;  // velocity derivative gain
    const float Kiv = 2.0f;  // velocity integral gain
    const int8_t desiredVel = 8;  // desired velocity in counts/10ms
    const int16_t EDGE_THRESHOLD = 200;  // counts from edge to trigger direction flip

    while(true){

        // Read reference counts and clamp to encoder counts for 180 degree pan and 45 degree tilt
        rawPRC = panRefCount.get();
        rawTRC = tiltRefCount.get();
        if (rawPRC < -4764) {
            rawPRC = -4764;
        }
        if (rawTRC > 0) {
            rawTRC = 0;
        }
        if (rawTRC < -524) {
            rawTRC = -524;
        } 
        if (rawPRC > 4764) {
            rawPRC = 4764;
        }

        // Serial << "Raw PRC: " << rawPRC; // output for debugging

        // calculate position errors
        panErr = rawPRC - enc1.getCount();
        tiltErr = rawTRC - enc2.getCount();

        // Check if we're in scanning mode (when reference is at an extreme value)
        // If close to edge, use velocity control to sweep back and forth
        if ((rawPRC >= 4744 || rawPRC <= -4744) && !fire.get()) {
            // Scanning mode: velocity sweep between edges
            long currentPanCount = enc1.getCount();
            int8_t currentVel = (currentPanCount - prevPanCount) / 10;  // counts per 10ms tick
            int8_t desiredVelSigned = moveToMax ? desiredVel : -desiredVel;
            int8_t velErr = desiredVelSigned - currentVel;
            
            // Accumulate integral error
            integralErr += velErr;
            // Anti-windup: clamp integral term
            if (integralErr > 100.0f) integralErr = 100.0f;
            if (integralErr < -100.0f) integralErr = -100.0f;
            
            float dVel = velErr - prevErr;
            prevErr = velErr;
            
            panSpeed = (int16_t)(velErr * Kpv + dVel * Kdv + integralErr * Kiv);
            
            // Clamp to max speed
            if (panSpeed > MAXSPEED) {
                panSpeed = MAXSPEED;
            } else if (panSpeed < -MAXSPEED) {
                panSpeed = -MAXSPEED;
            }
            
            // Check for direction flip at edges
            if (currentPanCount >= 4764 - EDGE_THRESHOLD) {
                moveToMax = false;  // start moving toward min
                integralErr = 0;    // reset integral on direction flip
            } else if (currentPanCount <= -4764 + EDGE_THRESHOLD) {
                moveToMax = true;   // start moving toward max
                integralErr = 0;    // reset integral on direction flip
            }
            
            prevPanCount = currentPanCount;
        } else {
            // Fire mode or tracking mode: position control
            D1 = (panErr - P1)*10;
            P1 = panErr;
            panSpeed = P1*Kp1 + D1*Kd1;

            if (panSpeed > MAXSPEED) {
                panSpeed = MAXSPEED;
            }
            else if (panSpeed < -MAXSPEED) {
                panSpeed = -MAXSPEED;
            }
        }

        // Tilt always uses position control
        D2 = (tiltErr - P2)*10;
        P2 = tiltErr;
        tiltSpeed = P2*Kp2 + D2*Kd2;

        if(tiltSpeed > MAXSPEED) {
            tiltSpeed = MAXSPEED;
        }
        else if (tiltSpeed < -MAXSPEED) {
            tiltSpeed = -MAXSPEED;
        }


        Motor1.driveMotor(abs(panSpeed), panSpeed > 0);
        Motor2.driveMotor(abs(tiltSpeed), tiltSpeed < 0);
        //Serial << "Spraying " << endl;

        
        // output for debugging
        // int32_t tiltRef = tiltRefCount.get();
        // long tiltCount = enc2.getCount();
        // int32_t panRef = panRefCount.get();
        // long panCount = enc1.getCount();
        // Serial << "tilt ref: " << tiltRef << " | " << tiltCount << endl;
        // Serial << "TR: " << tiltRef << " | TC: " << tiltCount << " || PR: " << panRef << " | PC: " << panCount << endl;
            

        vTaskDelay(10); // Task Period of 10 ms
    }
 }

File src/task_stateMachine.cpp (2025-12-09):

/** @file task_stateMachine.cpp
 * 
 * @brief State machine task that manages system operation modes
 * @author Jackson Cordova, GPT5-mini
 * @date December 2025
 */

#include "PrintStream.h"
#include "shares.h"

#define CPP 17.5 // counts per pixel
#define WIDTH 32 // number of pixels in width
#define HEIGHT 24 // number of pixels in height


/** @brief State machine task
  * @details This task manages the different states of the system. 
  * State 0 is an initialization state which sets all shares to default. 
  * State 1 is a scanning state where the system looks back and forth for hot spots.
  * State 2 is a tracking state where the system points the thermal camera and hose
  * towards the detected hot spot and activates the spray mechanism. The task
  * period is set to 100 ms.
  * 
  * @param p_params not used and should be set to void in the xTaskCreate call
  */
void task_stateMachine(void* p_params) {
    uint8_t state = 0;
    uint8_t hour = 0;
    uint8_t panInd, tiltInd;
    pinMode(5, OUTPUT); // solenoid pin for spraying 
    digitalWrite(5, LOW);
    bool one_time_val = false;
    long now;
    int16_t panIndAway;

    while(true) {
        // Serial << "state: " << state << " ";
        switch(state) {
            case 0:
                // init state
                panRefCount.put(-4764);
                tiltRefCount.put(0);
                fire.put(false);
                spray.put(false);
                Serial << "System Initialized" << endl;
                digitalWrite(5, LOW);
                state = 1;
                
                break;
            case 1:
                if (fire.get()) {
                    Serial << "Fire Detected" << endl;
                    state = 2;
                } 
                tiltRefCount.put(0);
                Serial << "scanning... " << endl;
                if (enc1.getCount() > 4744) {
                    panRefCount.put(-4764);
                }
                if (enc1.getCount() < -4744) {
                    panRefCount.put(4764);
                }
                

                break;
            case 2:
                tiltInd = hotIndex.get() % WIDTH; // getting pixel index in tilt direction
                panInd = hotIndex.get() / WIDTH; // getting pixel index in pan direction 

                // setting pan and tilt reference counts based on hot spot location

                panIndAway = (panInd-HEIGHT/2);
                if (abs(panIndAway) < 3) {
                    panIndAway = 0;
                }

                panRefCount.put(enc1.getCount() + panIndAway*CPP*50/22);
                
                if (enc2.getCount() > -20) {
                    tiltRefCount.put(-524);
                }
                else if (enc2.getCount() < -504) {
                    tiltRefCount.put(0);
                }


                if (panIndAway == 0 && fire.get() && !one_time_val) {
                    Serial << "Activating Spray!" << endl;
                    spray.put(true);
                    digitalWrite(5, HIGH); // activate solenoid
                    one_time_val = true;
                    now = millis();
                }

                if (millis() - now > 10000 && one_time_val) {
                    Serial << "Deactivating Spray!" << endl;
                    spray.put(false);
                    digitalWrite(5, LOW); // deactivate solenoid
                    one_time_val = false;
                    Motor2.brakeMotor();
                }

                if (!fire.get() && !spray.get()) {
                    Serial << "Fire Out, Returning to Scan" << endl;
                    panRefCount.put(-4764);
                    tiltRefCount.put(0);
                    state = 1;
                }
                break;
            default:
                // more stuff
                break;
        }
        vTaskDelay(100);
    }

}

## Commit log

2025-10-16 deleted: board/EMBER.kicad_sch new file: board/ME507-EMBER/ME507-EMBER-backups/ME507-EMBER-2025-10-03_110047.zip new file: board/ME507-EMBER/ME507-EMBER-backups/ME507-EMBER-2025-10-08_101237.zip new 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
    [EMBER.kicad_sch, ME507-EMBER.kicad_pcb, ME507-EMBER.kicad_sch]
2025-10-17 new file: board/ME507-EMBER/~ME507-EMBER.kicad_sch.lck
2025-10-17 modified: board/ME507-EMBER/ME507-EMBER.kicad_sch deleted: board/ME507-EMBER/~ME507-EMBER.kicad_sch.lck
    [ME507-EMBER.kicad_sch]
2025-10-23 modified: EMBER/src/main.cpp new file: board/ME507-EMBER/ME507-EMBER-backups/ME507-EMBER-2025-10-19_140626.zip modified: board/ME507-EMBER/ME507-EMBER.kicad_sch
    [ME507-EMBER.kicad_sch]
2025-10-24 new file: board/ME507-EMBER/ME507-EMBER-backups/ME507-EMBER-2025-10-23_172612.zip modified: board/ME507-EMBER/ME507-EMBER.kicad_pcb modified: board/ME507-EMBER/ME507-EMBER.kicad_prl modified: board/M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
    [ME507-EMBER.kicad_pcb, ME507-EMBER.kicad_sch]
2025-10-25 new file: board/ME507-EMBER/EMBER_Footprints.pretty/EMBER_Vishay_PowerPAK_1212-8.kicad_mod new file: board/ME507-EMBER/EMBER_Footprints.pretty/MOSFET_Vishay_PowerPAK_1212-8_Single_JACKSON.kicad_mod n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
    [ME507-EMBER.kicad_pcb, ME507-EMBER.kicad_sch]
2025-10-28 deleted: board/ME507-EMBER/ME507-EMBER-backups/ME507-EMBER-2025-10-24_173205.zip new file: board/ME507-EMBER/ME507-EMBER-backups/ME507-EMBER-2025-10-24_181717.zip new file: board/ME507-EMBER/ME507-EM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
    [ME507-EMBER.kicad_pcb, ME507-EMBER.kicad_sch]
2025-10-30 new file: board/ME507-EMBER/ME507-EMBER-backups/ME507-EMBER-2025-10-30_154305.zip new file: board/ME507-EMBER/ME507-EMBER-backups/ME507-EMBER-2025-10-30_160009.zip new file: board/ME507-EMBER/ME507-E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
    [ME507-EMBER.kicad_pcb, ME507-EMBER.kicad_sch]
2025-11-06 modified: EMBER/src/main.cpp new file: board/ME507-EMBER/EmberGerb.zip new file: board/ME507-EMBER/EmberGerb/ME507-EMBER-B_Cu.gbl new file: board/ME507-EMBER/EmberGerb/ME507-EMBER-B_Mask.gbs new file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
    [ME507-EMBER-B_Cu.gbl, ME507-EMBER-B_Mask.gbs, ME507-EMBER-B_Paste.gbp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]
2025-11-07 new file: EMBER/src/DRV8871Driver.cpp new file: EMBER/src/DRV8871Driver.h modified: EMBER/src/main.cpp DRV8871Driver to control motor driver, needs to be tested.
2025-11-10 modified: EMBER/src/DRV8871Driver.cpp modified: EMBER/src/DRV8871Driver.h new file: board/ME507-EMBER/ME507-EMBER-backups/ME507-EMBER-2025-11-06_174039.zip modified: board/ME507-EMBER/ME507-EMBER.kic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
2025-12-04 modified: EMBER/src/task_motorControl.cpp modified: EMBER/src/task_read_camera.cpp modified: EMBER/src/task_stateMachine.cpp modified: EMBER/src/task_webserver.cpp deleted: board/ME507-EMBER/~ME507-E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
2025-12-06 hardware folder for board and cad
2025-12-08 deleted: board/ME507-EMBER/EmberGerb.zip renamed: board/ME507-EMBER/EMBER_Footprints.pretty/EMBER_Vishay_PowerPAK_1212-8.kicad_mod -> hardware/board/EMBER_Footprints.pretty/EMBER_Vishay_PowerPAK_1212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
    [ME507-EMBER-B_Cu.gbl, ME507-EMBER-B_Mask.gbs, ME507-EMBER-B_Paste.gbp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]
2025-12-08 deleted: EMBER/hardware/board/README
2025-12-09 new file: hardware/board/Board.pdf new file: hardware/board/Schematic.pdf
2025-12-09 Revise README with EMBER mechanical components details
    Updated the README to include detailed descriptions of EMBER mechanical components and their assembly files.
2025-12-09 new file: hardware/board/Board_3D.png
